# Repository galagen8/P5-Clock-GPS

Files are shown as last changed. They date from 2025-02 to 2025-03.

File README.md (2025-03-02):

<h1>P5 Clock GPS</h1>
P5 Clock GPS
P5 LED 3x3 pcs Clock getting time and date from GPS satellite. </br> </br>
To built this clock I used P5 LED RGB. But customer wants only White color in text. 
</br>
The clock screen supposed to looks like this:
</br></br>
<p align="center">

</p>

Provided drawing for the case. You can find drawing files it in "Solidworks files" directory:

</br>
<p align="center">

</p>

Connection scheme:

<p align="center">

</p>

Provided PCB for the clock. I used STM32 BluePill development board and Neo-6M GPS-Module. You can find all PCB files in "Altium files" directory. Also you can find PDF-schemes in "Schemes" folder.

<p align="center">

</p>
<p align="center"> PCB front </p>

<p align="center">

</p>
<p align="center"> PCB back </p>

Manufactured PCB:
<p align="center">

</p>

Backside assembly:
<p align="center">

</p>

From the front:
<p align="center">

</p>

For programming I used **DMD_STM32 library**. It just works and library owner always provides feedback. </br>
You can download it there: https://github.com/board707/DMD_STM32 . </br>

Two fonts were created: big is to show the time, smaller - to show the date. Both of them are in "Fonts" folder. </br>

Also one thing: better to find Px LED module which is supported by library. Please check up what shift-register ICs are used in your LED module before you order. </br>

The clock uses external antenna. So you have to keep in mind about correct antenna placement - it doesn't get any data from satellite if there is any obstacle between antenna and satellite:

<p align="center">

</p>

Installed clock photo:
<p align="center">

</p>

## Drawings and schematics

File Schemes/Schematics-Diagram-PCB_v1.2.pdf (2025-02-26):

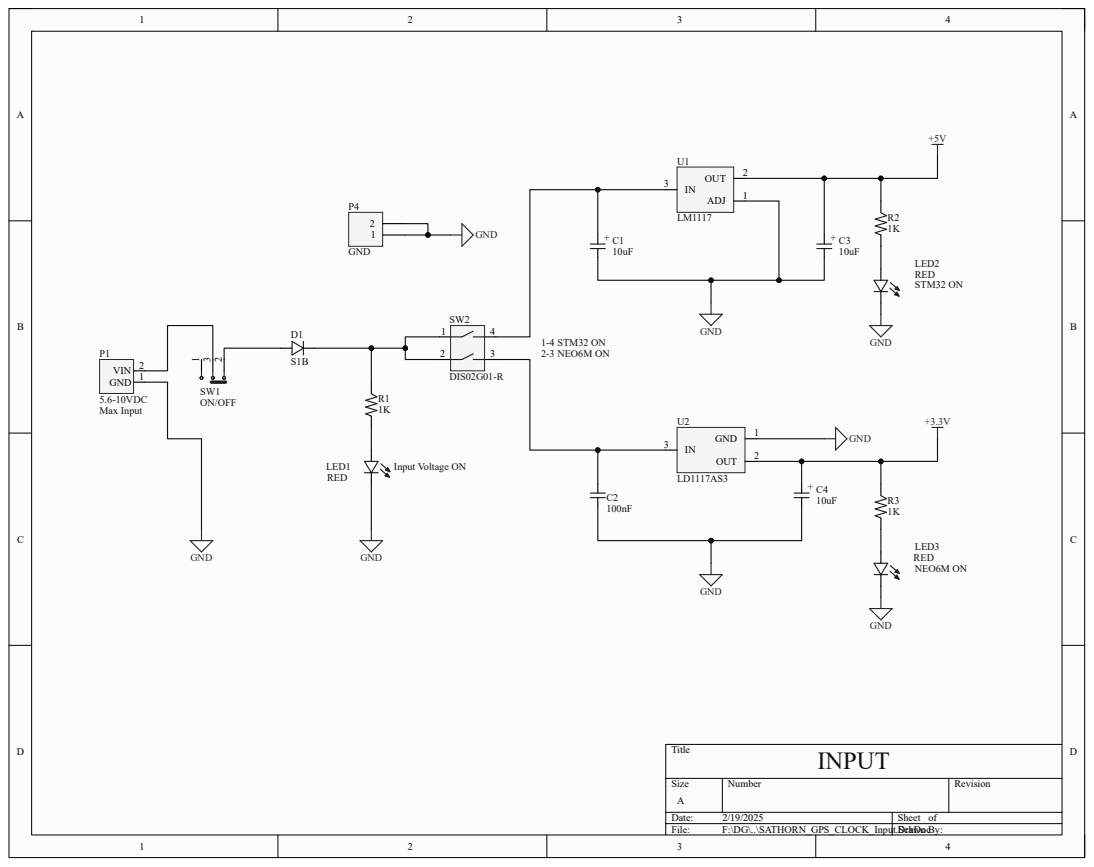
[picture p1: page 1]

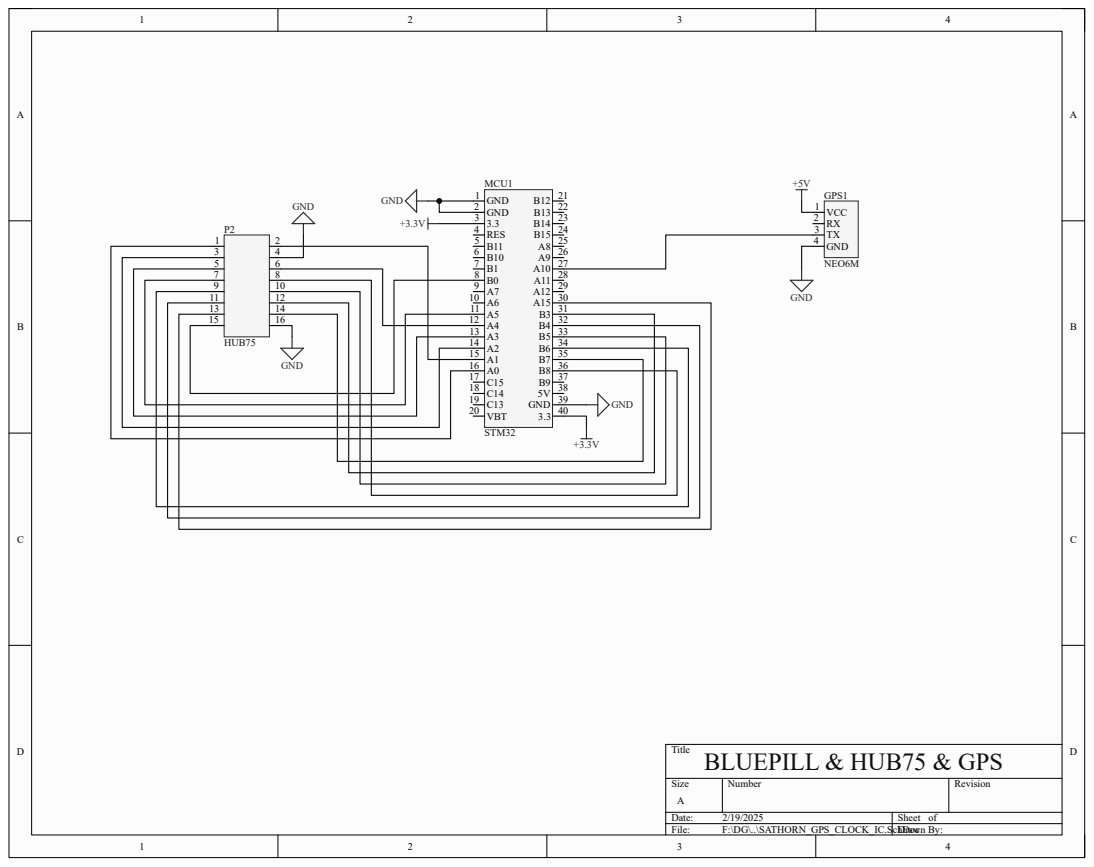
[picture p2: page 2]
Title; Size; Number; Revision; Date:; Sheet of; File:; F:\DG\..\SATHORN_GPS_CLOCK_IC.SchDoc Drawn By:; GND 1 GND 2 3.3 3 RES 4 B11 5 B10 6 B1 7 B0 8 A7 9 A6 10 A5 11 A4 12 A3 13 A2 14 A1 15 A0 16 C15 17 C14 18 C13 19 VBT 20; B12 21 B13 22 B14 23 B15 24 A8 25 A9 26 A10 27 A11 28 A12 29 A15 30 B3 31 B4 32 B5 33 B6 34 B7 35 B8 36 B9 37 5V 38 GND 39 3.3 40; MCU1; STM32; GND; HUB75; BLUEPILL & HUB75 & GPS; VCC 1 RX 2 TX 3 GND 4; GPS1; NEO6M

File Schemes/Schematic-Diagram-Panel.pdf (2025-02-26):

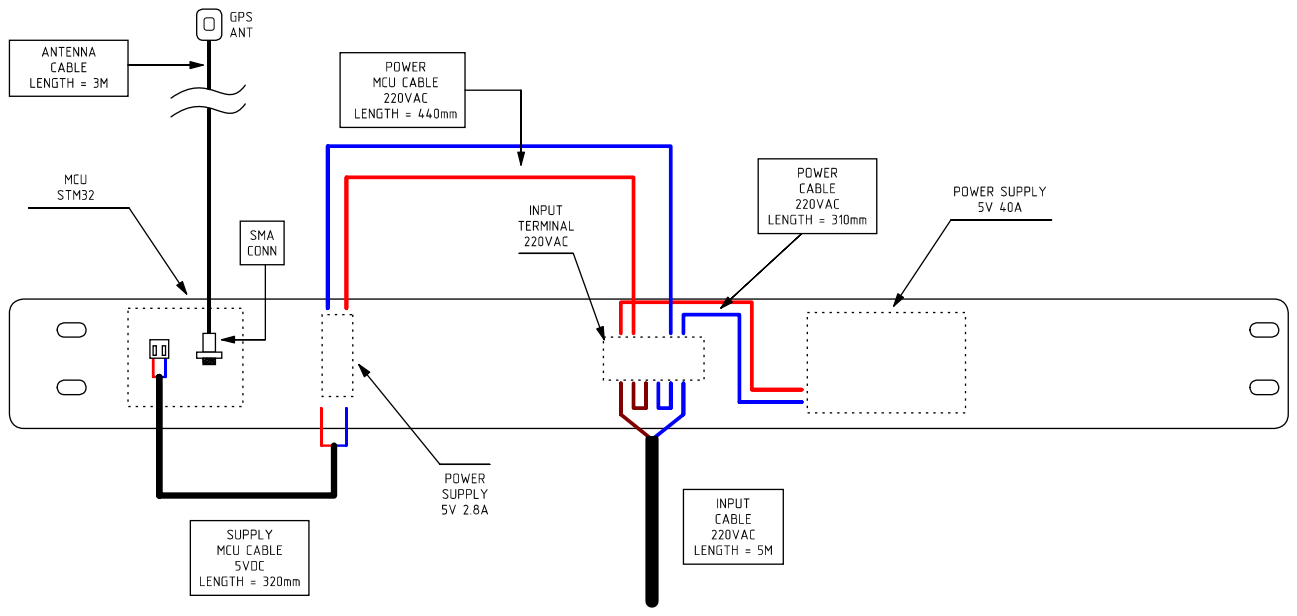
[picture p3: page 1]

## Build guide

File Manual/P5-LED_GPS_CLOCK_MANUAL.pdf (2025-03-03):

# GPS CLOCK 3x3 P5 LED MODULE MANUAL V1.2

Provided by Alex Kaledinov

alexkaledinov1@gmail.com

DESCRIPTION and PARAMETERS:

The CLOCK gets current date and time from GPS-Satellite and automatically renews it every 1 second.

CLOCK Parameters:

Clock Dimensions: | 487mm(H) x 960mm(W) x 140mm(D)
LED Module Quantity: | 9 pcs
Mounting Type: | Bolts or Screws
Voltage: | 220-230VAC
Power Consumption: | 4.5A max
Screen Resolution: | 192px(W) x 96px(H)
Color mode: | RGB 1-bit mode

LED Module Parameters:
Module Type: | Outdoor P5 SMD2525 5VDC 75W
Module Dimension: | 320mm(L) x 160mm(H) x 25mm(D)
Module Resolution: | 64px(L) x 32px(H)
Pixel Pitch: | 5mm
Scan Rate: | 1/8 Scan
Module ICs: | ICN2012, ICN2037BP, MW245B
Brightness: | 6000 cd/m2
Working Temperature: | -20~+60 ºC
Working Humidity: | 10%~90% RH
Protection: | Water-Resistant

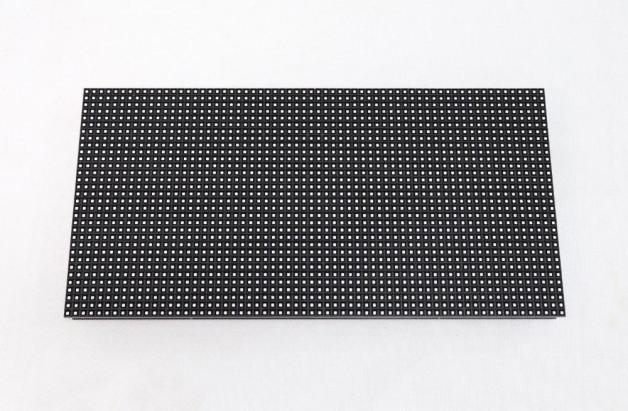
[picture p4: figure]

GPS Antenna Parameters:
Direction: | Omni-Directional
Mounting: | Magnetic base
Cable Length: | 3 meters
Connector type: | SMA
Frequency: | 1575.42MHz
Voltage: | 3-5VDC
Current: | 20mA Max
Resistance: | 50Ω

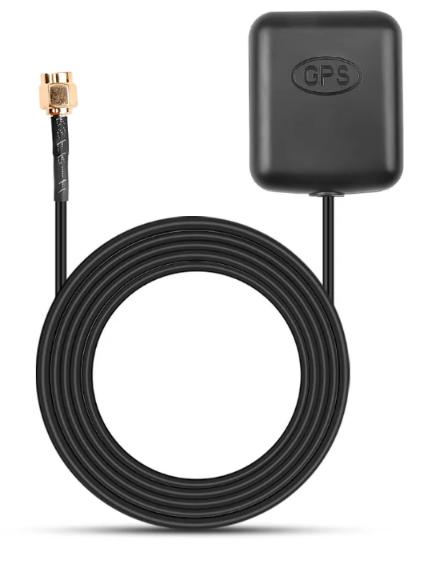
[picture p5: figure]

Power Supply Parameters for LED:
Brand: | Mean Well
Model: | LRS-350-5
Voltage: | 5V
Current: | 60A

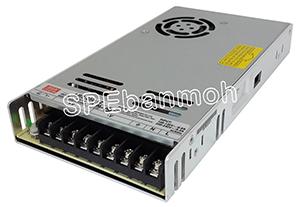
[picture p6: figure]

Power Supply Parameters for MCU:
Brand: | Mean Well
Model: | LRS-35-5
Voltage: | 5V
Current: | 7A

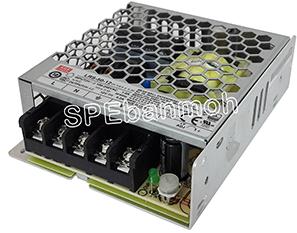
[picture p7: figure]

SCREEN and FONTS:

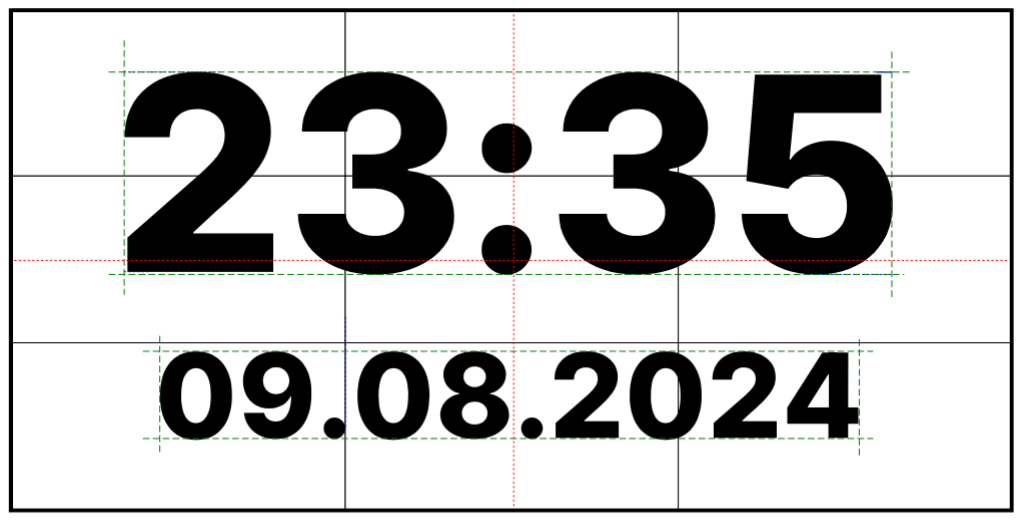
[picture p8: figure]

BACKSIDE PHOTO:

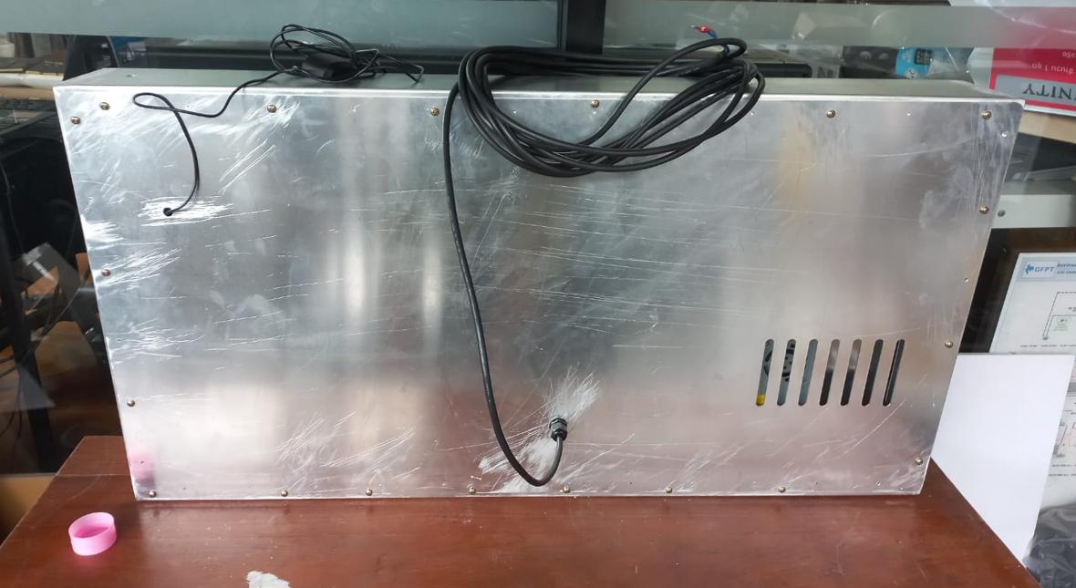
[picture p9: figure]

BACKSIDE ASSEMBLY:

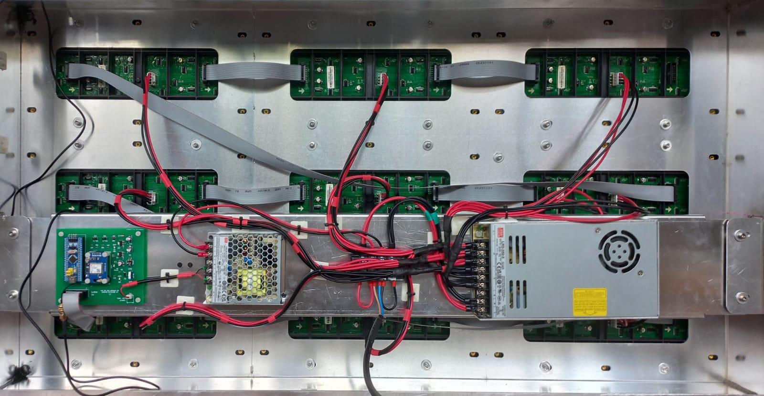
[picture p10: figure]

WIRING AND CONNECTIONS:

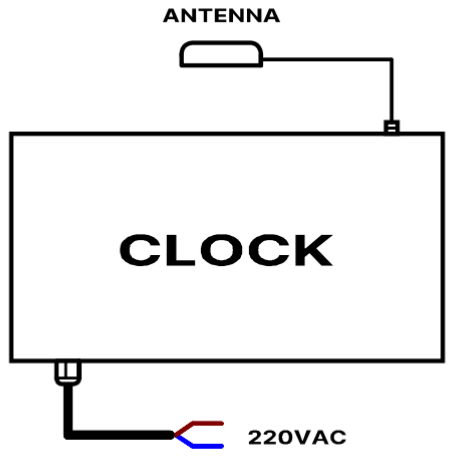
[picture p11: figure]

CORRECT ANTENNA INSTALLATION:

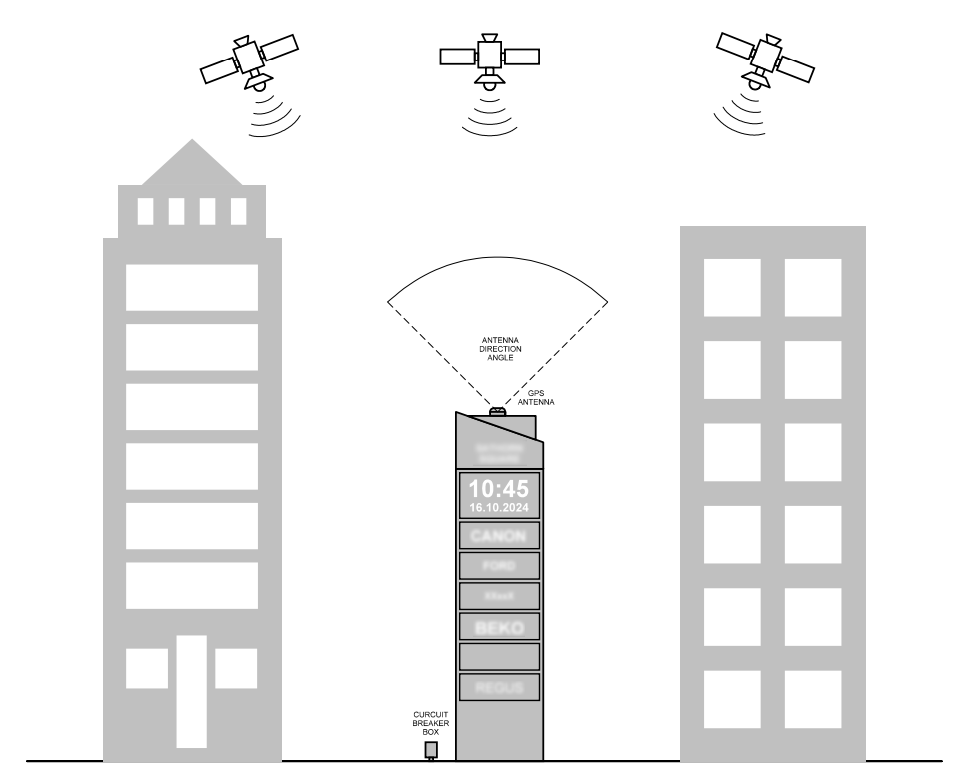
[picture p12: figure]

No obstacles between antenna and sky!

USAGE:

1. Just connect clock power cable to grid. The screen will show time “07:00” and date “00.00.2000”.
2. Wait around 10-40 sec. When CLOCK will catch a few satellites, screen will start to show the real current time and date.
3. If during exploitation you ‘ve noticed some weird things on the screen (for instance: wrong date/time, flickers, etc.) – needed to provide hard reset. To do it, please turn off Circuit Breaker located nearby the Signage Pylon, leave it and wait. After 20 seconds that you can switch it on again:

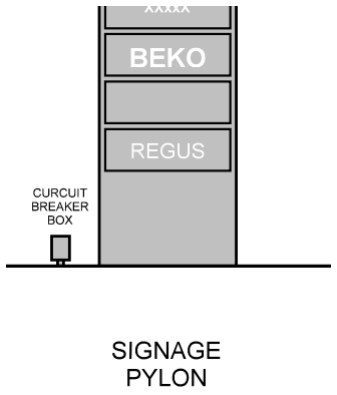
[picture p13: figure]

If it doesn’t helps – please, contact to your supplier.

MAINTENANCE and SERVICE:

EVERY 1/2 YEAR or ONE YEAR | Clean the screen from dust with water and soft cloth. Don’t use any aggressive solvents and rough cloth!
EVERY 5-6 YEARS | Replace all LED-modules.
EVERY 8 YEARS | Replace all Power Suppliers inside the CLOCK case.

Alex Kaledinov 2025 (c)

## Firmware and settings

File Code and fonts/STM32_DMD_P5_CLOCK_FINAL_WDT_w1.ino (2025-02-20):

/*--------------------------------------------------------------------------------------
 Demo for RGB panels

 DMD_STM32a example code for STM32F103xxx board
 ------------------------------------------------------------------------------------- */
#include "DMD_RGB.h"
#include "TinyGPSPlus.h"

// add new template panel
#define RGB64x32plainS8 4,64,32,8,3 // 64x32 1/8

// create GPS odject
TinyGPSPlus gps;

// Fonts includes
#include "st_fonts/InterExtraBold_50.h"
#include "st_fonts/InterExtraBold_19.h"

//Number of panels in x and y axis
#define DISPLAYS_ACROSS 3
#define DISPLAYS_DOWN 3

// Enable of output buffering
// if true, changes only outputs to matrix after
// swapBuffers(true) command
// If dual buffer not enabled, all output draw at matrix directly
// and swapBuffers(true) cimmand do nothing
#define ENABLE_DUAL_BUFFER false

// ==== DMD_RGB pins ====
// mux pins - A, B, C... all mux pins must be selected from same port!
#define DMD_PIN_A PB6
#define DMD_PIN_B PB5
#define DMD_PIN_C PB4
#define DMD_PIN_D PB3
#define DMD_PIN_E PB8

// put all mux pins at list
uint8_t mux_list[] = { DMD_PIN_A , DMD_PIN_B , DMD_PIN_C , DMD_PIN_D , DMD_PIN_E };

// pin OE must be one of PB0 PB1 PA6 PA7
#define DMD_PIN_nOE PB0
#define DMD_PIN_SCLK PB7

// Pins for R0, G0, B0, R1, G1, B1 channels and for clock.
// By default the library uses RGB color order.
// If you need to change this - reorder the R0, G0, B0, R1, G1, B1 pins.
// All this pins also must be selected from same port!
uint8_t custom_rgbpins[] = { PA15, PA0,PA1,PA2,PA3,PA4,PA5 }; // CLK, R0, G0, B0, R1, G1, B1

// Fire up the DMD object as dmd<MATRIX_TYPE, COLOR_DEPTH>
// We use 64x32 matrix with 16 scans and 4bit color:
DMD_RGB <RGB64x32plainS8, COLOR_1BITS> dmd(mux_list, DMD_PIN_nOE, DMD_PIN_SCLK, custom_rgbpins, DISPLAYS_ACROSS, DISPLAYS_DOWN, ENABLE_DUAL_BUFFER);
// Color depth - <COLOR_4BITS_Packed>, <COLOR_4BITS> or <COLOR_1BITS>

// --- Define fonts ----
// DMD.h old style font
DMD_Standard_Font InterExtraBold50_F(InterExtraBold50);
DMD_Standard_Font InterExtraBold19_F(InterExtraBold19);

// fixcount var
uint8_t fixCount = 0;

// basic colors for 1BIT mode
long color_black = 0x0000;     // black color
long color_blue = 0x001F;      // blue color
long color_red = 0xF800;       // red color
long color_green = 0x07E0;     // green color
long color_cyan = 0x07FF;      // cyan color
long color_magenta = 0xF81F;   // white color
long color_yellow = 0xFFE0;    // yellow color
long color_white = 0xFFFF;     // white color

// TIME coordinates variables
int xspace_time = 15;
int yspace_time = 13;

// DATE coordinates variables
int xspace_date = 13;
int yspace_date = 64;

// Time and Date data variables
int rxhours;
int rxmin;
int rxday;
int rxmonth;
int rxyear;

// GMT correction for Asia BKK time
int GMT = 7;

//  real digits for DMD and LCD
int digit1;  // 1st digit for hours
int digit2;  // 2nd digit for hours
int digit3;  // 1st digit for minutes
int digit4;  // 2nd digit for minutes
int digit5;  // 1st digit for date
int digit6;  // 2nd digit for date
int digit7;  // 1st digit for month
int digit8;  // 2nd digit for month
int digit9;  // 1st two digits for year
int digit10; // 2nd two digits for year

// Arduino timer variables
unsigned long previousMillis = 0;  // will store last time when arduino timer was updated
const long interval = 1000;        // arduino timer interval in ms

//  ***************************************************
//  WatchDog Timer (WDT) example for STM32F10* BluePill
//  Formula I used:
//  RL = (Time[2000ms] * LSI_Clock[32k]) : (4 * 2^PR[3] * 1000) - 1 ;
//  Time - WDT Timeout in ms;
//  LSI_Clock - for BluePill (STM32F103C8) here is crystal 32,768 Hertz. I approxed this value to 32,000;
//  PR - Prescaler, refer to #define lines below. If the prescaler "4" is chosen, use "IWDG_PRE_64" in func "iwdg_init(prescaler, y)";
//  RL - computed value, which needed be set inside "reload" variable in func "iwdg_init(x, reload)";
//  NOTE: RL value CANNOT be more than 4095 !!!
//  P.S. As I see, WDT Timeout has became not exactly 2 sec, it's less - it's about 1600-1800ms.

#define LIBMAPPLE_CORE //comment it for HAL based core

#define IWDG_PR_DIV_4 0x0
#define IWDG_PR_DIV_8 0x1
#define IWDG_PR_DIV_16 0x2
#define IWDG_PR_DIV_32 0x3
#define IWDG_PR_DIV_64 0x4
#define IWDG_PR_DIV_128 0x5
#define IWDG_PR_DIV_256 0x6

typedef enum iwdg_prescaler 
{
  IWDG_PRE_4 = IWDG_PR_DIV_4,     /**< Divide by 4 */
  IWDG_PRE_8 = IWDG_PR_DIV_8,     /**< Divide by 8 */
  IWDG_PRE_16 = IWDG_PR_DIV_16,   /**< Divide by 16 */
  IWDG_PRE_32 = IWDG_PR_DIV_32,   /**< Divide by 32 */
  IWDG_PRE_64 = IWDG_PR_DIV_64,   /**< Divide by 64 */
  IWDG_PRE_128 = IWDG_PR_DIV_128, /**< Divide by 128 */
  IWDG_PRE_256 = IWDG_PR_DIV_256  /**< Divide by 256 */
} iwdg_prescaler;

#if defined(LIBMAPPLE_CORE)
typedef struct iwdg_reg_map {
  volatile uint32_t KR;  /**< Key register. */
  volatile uint32_t PR;  /**< Prescaler register. */
  volatile uint32_t RLR; /**< Reload register. */
  volatile uint32_t SR;  /**< Status register */
} iwdg_reg_map;

#define IWDG ((struct iwdg_reg_map *)0x40003000)
#endif

//  func to feed WatchDog: just reset WDT timer, must be in Arduino loop
void iwdg_feed(void)
{ 
  IWDG->KR = 0xAAAA; 
}

//  set WDT timer(timeout time)
void iwdg_init(iwdg_prescaler prescaler, uint16_t reload)
{
  IWDG->KR = 0x5555;
  IWDG->PR = prescaler;
  IWDG->RLR = reload;
  IWDG->KR = 0xCCCC;
  IWDG->KR = 0xAAAA;
}
//  **********************
//  **********************
//  end of WDT description


/*--------------------------------------------------------------------------------------
  setup
  Called by the Arduino architecture before the main loop begins
--------------------------------------------------------------------------------------*/

void setup(void)
{
  //  initialize DWT timer and set the timeout
  iwdg_init(IWDG_PRE_64, 999);

  // uncomment line below if you using St-Link with STM32F103xx boards
  enableDebugPorts();
  
  // initialize DMD objects
	dmd.init();

  // set connection scheme
  dmd.setConnectScheme(CONNECT_NORMAL);
  
  // set the brightness
  dmd.setBrightness(50);

  // clear screen
  dmd.clearScreen(true);

  // enable Serial UART transmission
  Serial1.begin(9600);  //  UART for NEO6M_GPS_Module
  Serial.begin(115200); //  STM32 UART RX(PA10) TX(PA9)

  // Just a message:
  Serial1.println("WDC was set at 2 seconds.");


}

/*--------------------------------------------------------------------------------------
  loop
  Arduino architecture main loop
--------------------------------------------------------------------------------------*/

void loop(void)
{
  iwdg_feed();  // reset WDT Timer
  Serial1.println("Loop goes on...");

  while (Serial1.available() > 0) 
  {
    gps.encode(Serial1.read());
    if (++fixCount >= 250) 
    {

      //  send time to Serial
      if (gps.time.isValid())
      {
      Serial.print(gps.time.hour());
      Serial.print(":");
      Serial.print(gps.time.minute());
      fixCount = 0;
      }

      gps.time; //  create GPS time object
      gps.date; //  create GPS date object

      rxhours = gps.time.hour() + GMT;  //  getting current hour + GMT hour correction
      rxmin = gps.time.minute();        //  getting current minute
      rxday = gps.date.day();           //  getting current day
      rxmonth = gps.date.month();       //  getting current month
      rxyear = gps.date.year();         //  getting current year

      //  GMT corrections
      if(rxhours > 23)
      {
          rxhours = rxhours - 24;

          if(rxmonth == 4 || rxmonth == 6 || rxmonth == 9 || rxmonth == 11)
          {
              if(rxday > 29)
              {
                  rxday = 1;
                  rxmonth = rxmonth + 1;
              }
              else
              {
                  rxday = rxday + 1;
              }
          }
          else if(rxmonth == 1 || rxmonth == 3 || rxmonth == 5 || rxmonth == 7 || rxmonth == 8 || rxmonth == 10 || rxmonth == 12)
          {
              if(rxday > 30)
              {
                  if(rxmonth == 12)
                  {
                      rxday = 1;
                      rxmonth = 1;
                      rxyear = rxyear + 1;
                  }
                  else
                  {
                      rxday = 1;
                      rxmonth = rxmonth + 1;
                  }
              }
              else
              {
                  rxday = rxday + 1;
              }
          }
          else
          {
              if(rxyear % 4 == 0)
              {
                  if(rxday > 28)
                  {
                      rxday = 1;
                      rxmonth = rxmonth + 1;
                  }
                  else
                  {
                      rxday = rxday + 1;
                  }
              }
              else
              {
                  if(rxday > 27)
                  {
                      rxday = 1;
                      rxmonth = rxmonth + 1;
                  }
                  else
                  {
                      rxday = rxday + 1;
                  }
              }
          }
      } //  end of GMT corrections 

      //  making hours here:
      if(rxhours < 10) 
      {
        digit1 = 0;
        digit2 = rxhours;
      }
      else if (rxhours > 19) 
      {
        digit1 = 2;
        digit2 = rxhours - 20;
      }
      else 
      {
        digit1 = 1;
        digit2 = rxhours - 10;
      }

      //making minutes
      if (rxmin < 10) 
      {        // here was < 9, needed to set < 10
        digit3 = 0;
        digit4 = rxmin;
      }
      else if (rxmin < 20) 
      {
        digit3 = 1;
        digit4 = rxmin - 10;
      }
      else if (rxmin < 30) 
      {
        digit3 = 2;
        digit4 = rxmin - 20;
      }
      else if (rxmin < 40) 
      {
        digit3 = 3;
        digit4 = rxmin - 30;
      }
      else if (rxmin < 50) 
      {
        digit3 = 4;
        digit4 = rxmin - 40;
      }
      else 
      {
        digit3 = 5;
        digit4 = rxmin - 50;
      }

      //making date
      if (rxday < 10) 
      {        // here was < 9, needed to set < 10
        digit5 = 0;
        digit6 = rxday;
      }
      else if (rxday < 20) 
      {
        digit5 = 1;
        digit6 = rxday - 10;
      }
      else if (rxday < 30) 
      {
        digit5 = 2;
        digit6 = rxday - 20;
      }
      else if (rxday < 40) 
      {
        digit5 = 3;
        digit6 = rxday - 30;
      }
      else if (rxday < 50) 
      {
        digit5 = 4;
        digit6 = rxday - 40;
      }
      else if (rxday < 60) 
      {
        digit5 = 5;
        digit6 = rxday - 50;
      }
      else if (rxday < 70) 
      {
        digit5 = 6;
        digit6 = rxday - 60;
      }
      else if (rxday < 80) 
      {
        digit5 = 7;
        digit6 = rxday - 70;
      }
      else if (rxday < 90) 
      {
        digit5 = 8;
        digit6 = rxday - 80;
      }

      //making month
      if(rxmonth < 10)
      {       // here was < 9, needed to set < 10
        digit7 = 0;
        digit8 = rxmonth;
      }
      else 
      {
        digit7 = 1;
        digit8 = rxmonth - 10;
      }

      //making year
      rxyear = rxyear - 2000;     // here was <9, needed to set <10
      if (rxyear < 10)
      {
        digit9 = 0;
        digit10 = rxyear;
      }
      else if (rxyear < 20)
      {
        digit9 = 1;
        digit10 = rxyear - 10;
      }
      else if (rxyear < 30)
      {
        digit9 = 2;
        digit10 = rxyear - 20;
      }
      else if (rxyear < 40)
      {
        digit9 = 3;
        digit10 = rxyear - 30;
      }
      else if (rxyear < 50)
      {
        digit9 = 4;
        digit10 = rxyear - 40;
      }
      else if (rxyear < 60)
      {
        digit9 = 5;
        digit10 = rxyear - 50;
      }
      else if (rxyear < 70)
      {
        digit9 = 6;
        digit10 = rxyear - 60;
      }
      else if (rxyear < 80)
      {
        digit9 = 7;
        digit10 = rxyear - 70;
      }
      else if (rxyear < 90)
      {
        digit9 = 8;
        digit10 = rxyear - 80;
      }

      // int to char conversion
      char chdigit1 = digit1 + '0'; //  char for hour
      char chdigit2 = digit2 + '0'; //  char for hour
      char chdigit3 = digit3 + '0'; //  char for min
      char chdigit4 = digit4 + '0'; //  char for min
      char chdigit5 = digit5 + '0'; //  char for day
      char chdigit6 = digit6 + '0'; //  char for day
      char chdigit7 = digit7 + '0'; //  char for month
      char chdigit8 = digit8 + '0'; //  char for month
      char chdigit9 = digit9 + '0'; //  char for year
      char chdigit10 = digit10 + '0'; //  char for year

      // top time frame 00:00
      dmd.selectFont(&InterExtraBold50_F);
      dmd.drawChar(0 + xspace_time, yspace_time, chdigit1, color_white, 0);    //  "1" digit
      dmd.drawChar(36 + xspace_time, yspace_time, chdigit2, color_white, 0);   //  "6" digit
      dmd.fillCircle(80 + xspace_time, 12 + yspace_time, 2, color_white);    //  "upper dot"
      dmd.fillCircle(80 + xspace_time, 27 + yspace_time, 2, color_white);    //  "lower dot"
      dmd.drawChar(91 + xspace_time, yspace_time, chdigit3, color_white, 0);  //  "3" digit
      dmd.drawChar(128 + xspace_time, yspace_time, chdigit4, color_white, 0);  //  "5" digit

      // bottom date frame 00.00.0000
      dmd.selectFont(&InterExtraBold19_F);
      dmd.drawChar(0 + xspace_date, yspace_date, chdigit5, color_white, 0);   //  "0" digit
      dmd.drawChar(18 + xspace_date, yspace_date, chdigit6, color_white, 0);  //  "9" digit
      dmd.fillRect(40 + xspace_date, 16 + yspace_date, 3, 3, color_white);
      dmd.drawChar(43 + xspace_date, yspace_date, chdigit7, color_white, 0);   //  "0" digit
      dmd.drawChar(63 + xspace_date, yspace_date, chdigit8, color_white, 0);   //  "8" digit
      dmd.fillRect(83 + xspace_date, 16 + yspace_date, 3, 3, color_white);
      dmd.drawChar(88 + xspace_date, yspace_date, 50, color_white, 0);   //  "2" digit
      dmd.drawChar(108 + xspace_date, yspace_date, 48, color_white, 0);   //  "0" digit
      dmd.drawChar(128 + xspace_date, yspace_date, chdigit9, color_white, 0);   //  "2" digit
      dmd.drawChar(148 + xspace_date, yspace_date, chdigit10, color_white, 0);   //  "4" digit
      //---------------------------------------------------------------------------------------
      // END OF EXECUTABLE CODE

    } // timer for MCU when to read serial from GPS

  } // if serial avaliable, we read Serial input from GPS
    
} // arduino loop bracket   
    

    

  
